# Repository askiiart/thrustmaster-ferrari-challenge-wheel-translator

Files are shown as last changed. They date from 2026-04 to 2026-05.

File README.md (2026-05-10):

# Thrustmaster FGT translator

This is a little microcontroller used to adjust pedals for the Thrustmaster Ferrari GT/Challenge wheel. It takes the potentiometer values, adjusts them to match that the controller expects, and outputs the values through the DACs to the rest of the controller.

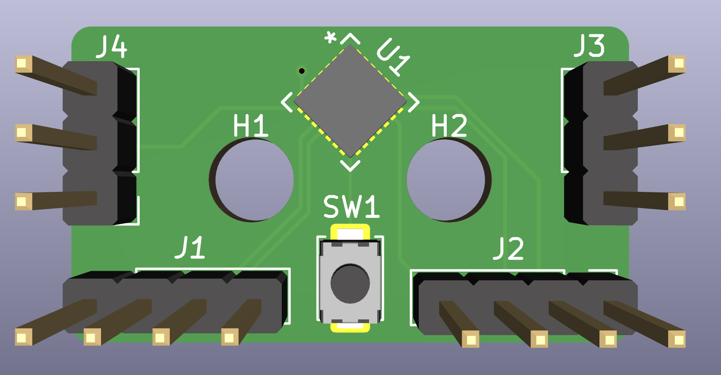
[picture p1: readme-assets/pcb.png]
render of the pcb


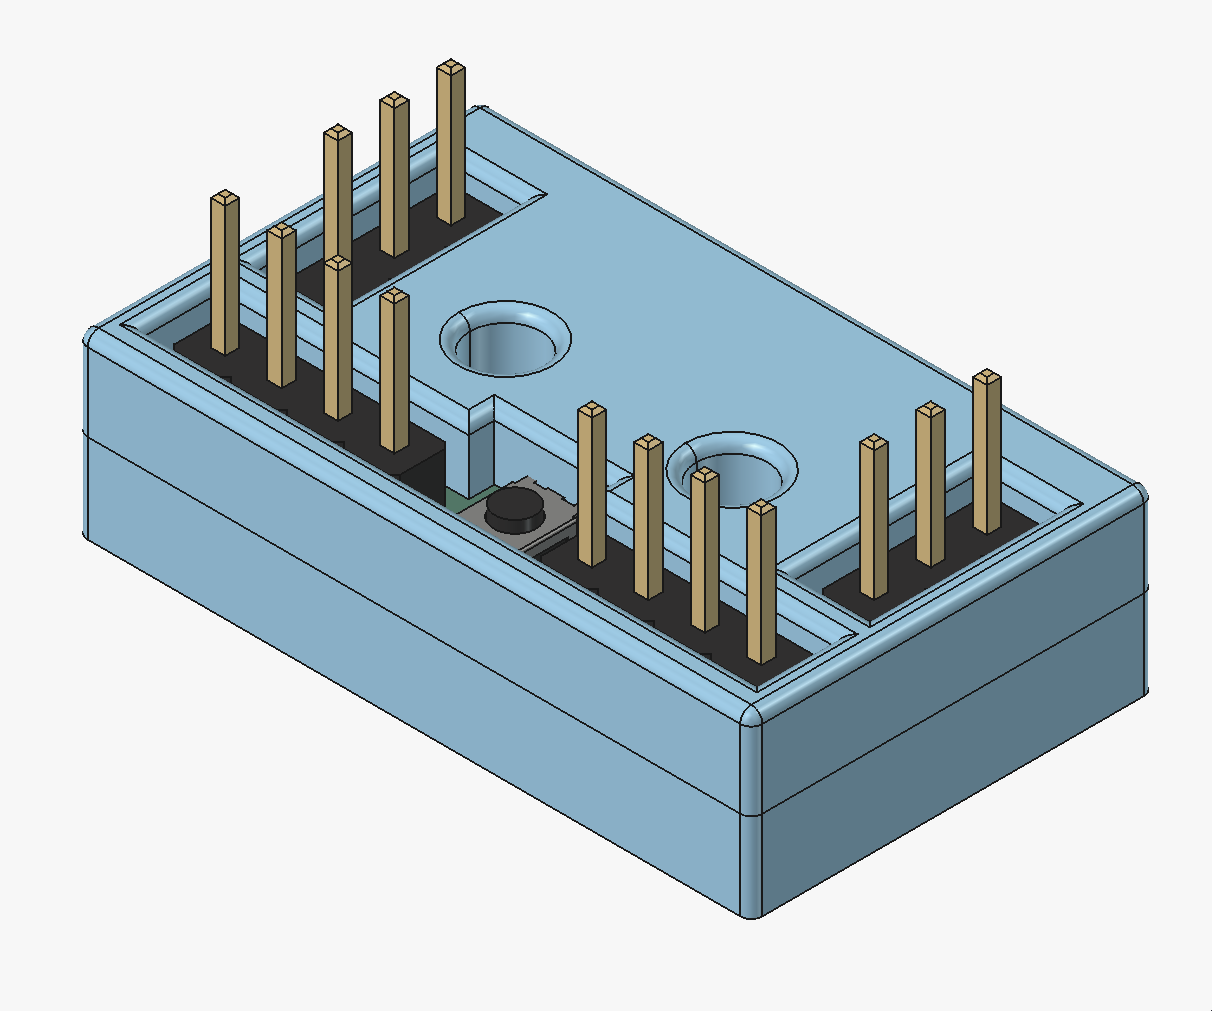
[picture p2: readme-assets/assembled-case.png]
render of it assembled with the case


## Parts

- STM32G071GBU6
- 1x 0402 100nF cap
- 1x 0402 4.7uF cap
- 1x TS-1088-AR02016 (switch)
- 2x 1x3 P2.54mm pinheaders
- 2x 1x4 P2.54mm pinheaders

## BOM

|Item |URL |Price |Quantity needed|Quantity to order|Total|
|---|---|---|---|---|-----|
|STM32G071GBU6 |<https://www.lcsc.com/product-detail/C529347.html> |1.65  |1 |1 |1.65 |
|100nF cap |<https://www.lcsc.com/product-detail/C60474.html>  |0.0011|1 |100 |0.11 |
|4.7uF cap |<https://www.lcsc.com/product-detail/C23733.html>  |0.0059|1 |50 |0.295|
|TS-1088-AR02016 (pushbutton)|<https://www.lcsc.com/product-detail/C720477.html> |0.0558|1 |10 |0.558|
|PZ254V-11-04P |<https://www.lcsc.com/product-detail/C2691448.html>|0.0254|2 |20 |0.508|
|PZ254V-11-03P |<https://www.lcsc.com/product-detail/C2937625.html>|0.0186|2 |50 |0.93 |
| | | | | | |
| | | | | | |
|Subtotal |4.06 | | | | |
|Shipping and handling |11.72 | | | | |
|PCB |5.22 | | | | |
| | | | | | |
|**Total** |22.7325 | | | | |

## Microcontroller 3D model

In accordance with the terms of SnapMagic's terrible license, I can't redistribute the microcontroller 3D model, hence it's not included. If you want it, it's on Digikey.

## CAD

All STEP files are provided in `./CAD/`. Design was done in Onshape, but assembly was done in FreeCAD. The assembly design file is in CAD, while here are the Onshape design files:

- [case top](https://cad.onshape.com/documents/4cd0723182fb444a0eb40fc6/w/16d03d3cdb549aa466cdaea8/e/f06282226fc81b6d0f6ad971)
- [case bottom](https://cad.onshape.com/documents/cf5c5eb7a78b451ade18eba2/w/7ba96a54e81cf9eb85f76eec/e/e2db873006224d9eaa981bd6)

I can't really test if just providing the links works so uh. Good luck, let me know if you can't access them.

## Wiring

The wiring is a 1-to-1 copy of the original board - wire the 4-pin to the left connector (J1, italicized). But for reference, this is the pinout of the RJ9 (board connector is the same)

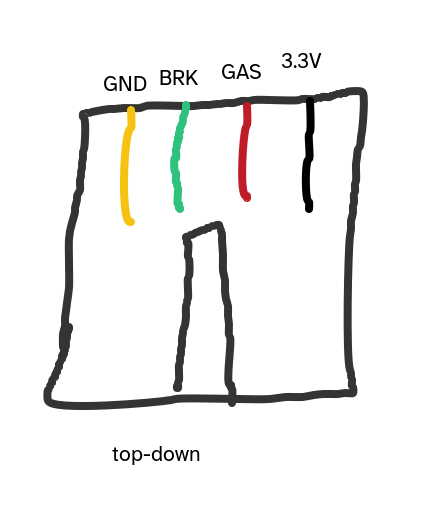
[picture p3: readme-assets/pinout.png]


And the pinout of the PCB:

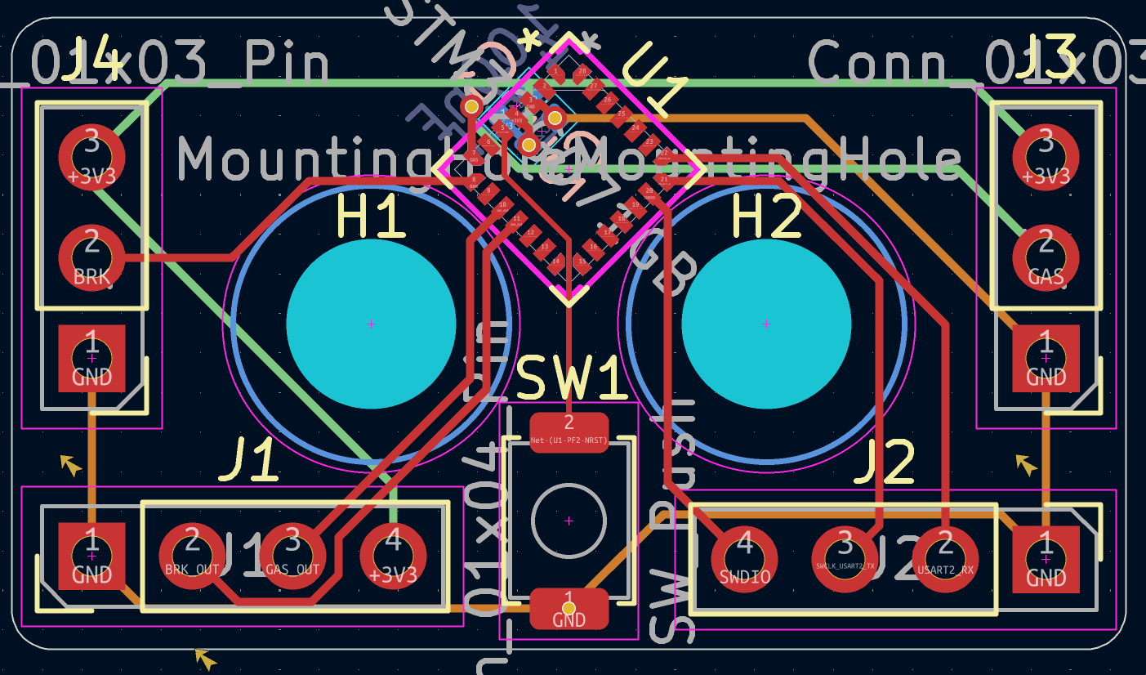
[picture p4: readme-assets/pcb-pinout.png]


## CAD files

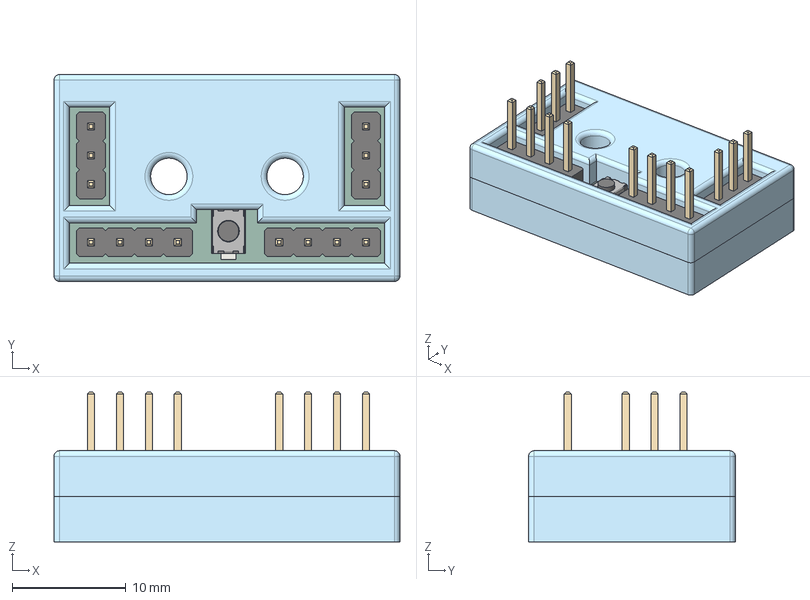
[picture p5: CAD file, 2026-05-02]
CAD/assembly.step
30.4 x 18.2 x 13.1 mm
SW_SPST_TS-1088-xR020
PinHeader_1x03_P2.54mm_Vertical
PinHeader_1x04_P2.54mm_Vertical
STM32G071GBU6
STM32G071GBU001
STM32G071GBU002
STM32G071GBU003
STM32G071GBU004
STM32G071GBU005
STM32G071GBU006
STM32G071GBU007
STM32G071GBU008
STM32G071GBU009
STM32G071GBU010
STM32G071GBU011
STM32G071GBU012
STM32G071GBU013
STM32G071GBU014
STM32G071GBU015
STM32G071GBU016
STM32G071GBU017
STM32G071GBU018
STM32G071GBU019
STM32G071GBU020
STM32G071GBU021
STM32G071GBU022
STM32G071GBU023
STM32G071GBU024
STM32G071GBU025
STM32G071GBU026
STM32G071GBU027
STM32G071GBU028
PinHeader_1x03_P2.54mm_Vertical001
PinHeader_1x04_P2.54mm_Vertical001
C_0402_1005Metric
C_0402_1005Metric001
translator_PCB

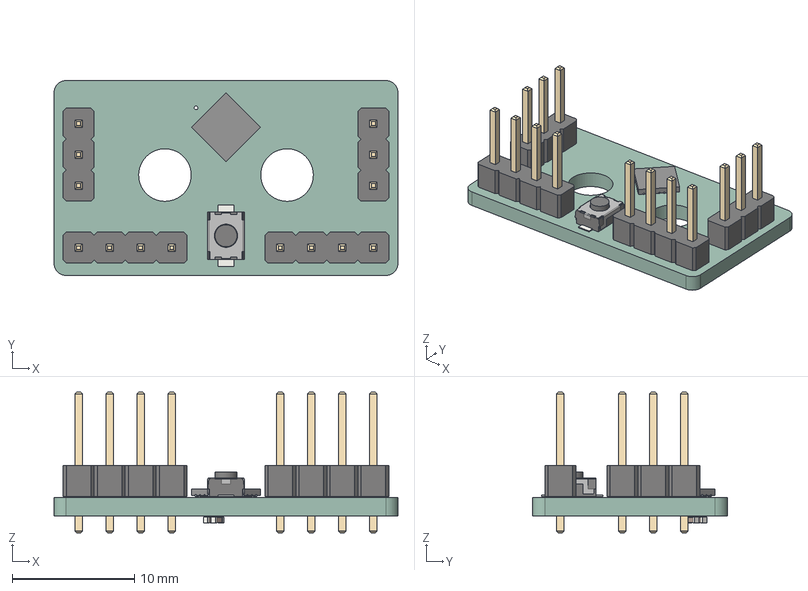
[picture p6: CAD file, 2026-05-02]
CAD/translator.step
28.2 x 16.0 x 11.5 mm
SW_SPST_TS-1088-xR020
PinHeader_1x03_P2.54mm_Vertical x 2
PinHeader_1x04_P2.54mm_Vertical x 2
STM32G071GBU6
C_0402_1005Metric x 2
translator_PCB

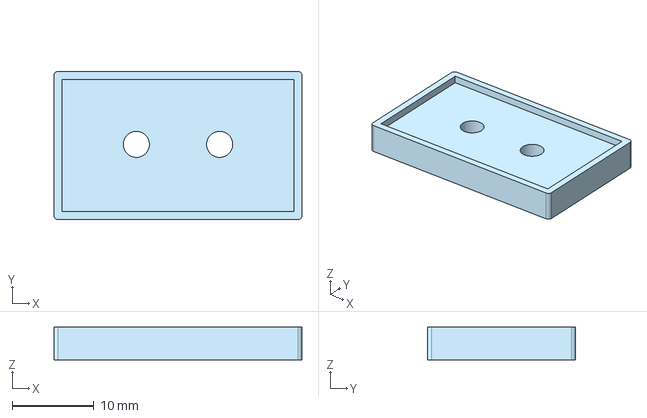
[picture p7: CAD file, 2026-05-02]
CAD/case-bottom.step
30.4 x 18.2 x 4.00 mm

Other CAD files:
CAD/case-top.step
CAD/assembly.FCStd

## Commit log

2026-04-09 add schematic and pedal pinout
    [translator.kicad_sch]
2026-04-23 add stuffs (pcb is done)
    [translator.kicad_pcb, translator.kicad_sch]
2026-04-26 actually finish pcb...?
    [translator.kicad_pcb]
2026-05-02 reorganize and add CAD
    [BOM.xlsx, assembly.FCStd, assembly.step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]
2026-05-03 add BOM and gerbers
    [BOM.xlsx]
2026-05-03 add pinouts for wiring
2026-05-05 oopssssss i forgot BOM.csv
    [BOM.csv]
2026-05-10 updated connectors slightly and updated readme
    [translator.kicad_pcb, translator.kicad_sch]
